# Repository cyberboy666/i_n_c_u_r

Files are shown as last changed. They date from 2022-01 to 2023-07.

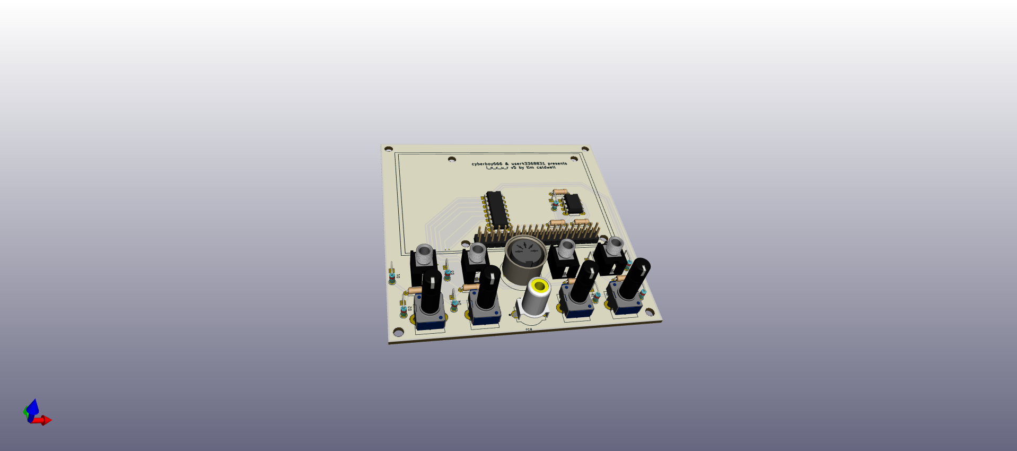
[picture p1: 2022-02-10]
incur_board_3d.png

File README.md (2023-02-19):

# i_n_c_u_r

### a [r_e_c_u_r](https://github.com/cyberboy666/r_e_c_u_r) video sampler extension circuit - adding knobs, cv and serial midi control



- this circuit is distributed by __UNDERSCORES__ - _an open video hardware label_ : it is available to purchase - as a pcb, kit or assembled unit - at [underscores.shop](https://underscores.shop/i_n_c_u_r/)
- the schematic for the circuit can be found [here](/hardware/schematic.pdf)
- the pcb gerber files for the lastest version can be found [here](/hardware/gerber_latest.zip)
- interactive BOM is [here](https://htmlpreview.github.io/?https://github.com/cyberboy666/i_n_c_u_r/blob/main/hardware/bom/ibom.html)
- consider [donating](https://opencollective.com/underscores) to the underscores project to help us continue creating for the commons

## description

__NOTE__ : _i_n_c_u_r_ is an extension circuit for my existing raspberry pi project [r_e_c_u_r](https://github.com/cyberboy666/r_e_c_u_r) - it will only be useful to you if you already have build a r_e_c_u_r

_disclaimer: this is a fun custom project, but dont forget there are other ways to getting serial and cv control over recur parameters. USB midi is supported in recur without any extra circuitry. other [diy](https://aemodular.boards.net/thread/141/simple-cv-midi-converter-arduino) and [commercial](https://www.befaco.org/en/vcmc/) products exist that convert cv to midi, and serial to USB. in my opinion a general solution for cv-to-usb-midi applied to recur is more useful than a specific board that only works with recur_

- 4x __knobs__ for physical control over shader parameters
- 4x __cv jacks (0-5v)__ for sequenced control over shader parameters (from older/analog synths eg eurorack)
- __serial midi__ din5 jack for sequenced control over shader parameters (from older midi devices)
- exposes _rpi video output through rca jack_ (rather than the 3.5mm trrs jack on pi )
- mounting holes and front facing interface parts for easier racking / enclosure building
- interfacing with rpi through gpio leaving all usb jacks free

## demo videos

(https://videos.scanlines.xyz/w/534XkPbbdpDNjTziM6pPNG)

(https://youtu.be/ah2HY1fuv8w?t=638)

# documentation

this project is fully _open-source hardware_ - all the files required to build it are included in this repo for free. if you have the time and/or skill you can contribute back by collaborating on / testing new designs, improving these docs, making demo videos/other creative content etc. you can also support the project financially by [donating directing](https://opencollective.com/underscores), or purchasing through the [web shop](https://underscores.shop).

depending on whether you are going fully diy or buying an assembled and tested unit, some of the following guides will be relavent to you. the flow would be:

## ordering parts

<details><summary><b>parts sourcing guide (w/ notes on pcb fabracation )</b> - start here if you are building fully from scatch or have purchased a pcb</summary>

i try to source all the parts i can from either:
- [tayda](https://www.taydaelectronics.com/) ; cheaper for common parts like resistors etc, also good for mechanical parts like switches and buttons
- [mouser](https://www.mouser.de/) ; has lots more options, speciality video ic's, can sometimes cost more (free shipping on orders over 50euros)
- other ; ocationally there will be parts which will need to be sourced elsewhere - usaully either aliexpress, ebay or amazon etc...

take a look at the [full_bom](/hardware/bom/full_bom.csv) for this project to see where i am sourcing each part from

## import into tayda

- go to the [tayda quick order](https://www.taydaelectronics.com/quick-order/) and in bottom corner choose _add from file_
- select the file [tayda_bom.csv](./hardware/bom/tayda_bom.csv) in the BOM folder (you will have to download it first or clone this repo)
- after importing select _add to cart_
- __NOTE:__ the minimum value for resistors is 10, so you may need to modify these values to add to cart (or if they are already modified here you will need to see the  full_bom for actual part QTY) 

- OPTIONAL: it is a good idea to add some dip-ic sockets and 2.54pin headers/sockets to your tayda order if you dont have them around already
  
## import into mouser

- go to [mouser bom tool](https://nz.mouser.com/Bom/) and click _upload spreadsheet_
- select the file [mouser_bom.csv](./hardware/bom/mouser_bom.csv) in this folder (you will have to download it first or clone this repo), then _upload my spreadsheet_ and _next_
- ensure that __Mouser Part Number__ is selected in the dropdown above the first row, then _next_, _process_
- if everything looks correct can now put _add to basket_

# ordering pcbs

you can support this project by buying individual pcbs from the [shop](https://underscores.shop). if you would rather have pcbs fabricated from gerbers directly the file you need is [here](/hardware/gerber_latest.zip) 

- i get my pcbs fabricated from [jlcpcb](https://cart.jlcpcb.com/quote) - 5 is the minumum order per design
- upload the zip file with the `add gerber file` button
- the default settings are mostly fine - set the __PCB Qty__ and __PCB Color__ settings (you can check that the file looks correct with pcb veiwer)
- it may be best to combine orders with other pcbs you want to have fab'd since the shipping can cost more than the items - also orginising group buys is a good way to distribute the extra pcbs /costs 
  
i often use jlcpcb because they are reliable, cheap and give you an option of colours. remember though that the cheapest Chinese fab houses are not always the most ethical or environmently friendly - if you can afford it consider supporting local companies. 

</details>

## assembly guide

<details><summary><b>assembly guide</b> - start here if you have purchased a diy kit</summary>

## interactive BOM for build guiding

follow this link to view the [interactive BOM](https://htmlpreview.github.io/?https://github.com/cyberboy666/i_n_c_u_r/blob/main/hardware/bom/ibom.html)

## general solder advices

- remember to heat pad first (2-3seconds), then add solder, then continue to heat (1-2seconds)

- Checkout the web-comic [soldering is easy](https://mightyohm.com/files/soldercomic/FullSolderComic_EN.pdf) for more soldering advice

## general order of assembly

- in general while assembling i start placing resistors and capacitors first. placing 5 - 10 components at a time and then flipping the board to solder them and trim the legs etc.
- next i would do diodes, transistors and ic's - taking care that these are placed in the right direction (using a ic socket can be useful)
- finally i place the interface parts - rca jacks, power jack, pots and switches - make sure these have lots of solder on for structural stablity

## slightly more specific assembly advice

start with the lowest to place components : resistors, diodes, ic's

next i would place the two headers since soldering from the top can be awkward with too many components - __NOTE these need to be placed upside down!__ ,:

- J8 needs the pins facing up from top of pcb so the screen can go ontop and raspberry pi can go underneath
- J6 also needs to soldered from the top so a jumper from the pi board can be run to bottom of circuit

finally place the pots and jacks.
  
### rca video-out

if you want RCA video out from the pi on this pcb a jumper needs to be run from J6 to the composite video out on the raspberry pi board. on pi0 this is a labeled pin, however on pi3 you will need to solder directly to the board. i used a header-cable, cut one side to be soldered. The pin on pi3 is marked as PP24.

 [picture coming soon]
  
</details>
  
## operating guide
  
<details><summary><b>operating guide</b> - start here if you have purchased an assembled unit</summary>



- to enable the analog inputs ( knobs & cv ) go to `user_input` folder in r_e_c_u_r's `_SETTINGS_` tab and toggle `ANALOG_INPUT`
- to enable serial midi input go to `user_input` folder in r_e_c_u_r's `_SETTINGS_` tab and toggle `MIDI_INPUT` to _serial_
  
for more info on operating r_e_c_u_r see this [guide](https://github.com/cyberboy666/r_e_c_u_r/wiki/operate_docs)

</details>

### more info

<details><summary><b>how the circuit works</b></summary>

</details>

<details><summary><b>contributing guide</b></summary>
  
if you would like to contribute back to these projects in some way but dont know how the best thing (for now) would be to reach out to me directly ( tim@cyberboy666.com or @cyberboy666 on scanlines forum) - i will be happy to help
  
</details>

## community contributed enclosure designs:

- an [eurorack panel design](enclosure/i_n_c_u_r%20_%20eurorack_panel.stl) by [Simon Gorzelnik](https://www.instagram.com/shimon.jpg/)
- a [base enclosure](enclosure/INCUR%20enclosure%20base.stl) by [miles](mailto:milesjohnsonwashere@gmail.com)

## credits & more info

This circuit is distributed through UNDERSCORES – open video hardware label – visit [underscores.shop](https://underscores.shop) for more info

The pcb was designed using KICAD

Everything from gerbers, cad files, panels and documentation is freely available online and distributed under CC-BY-SA / open-source licenses – help us contribute to the commons !

Ask any questions or start discussions related to this project on the [scanlines.xyz](https://scanlines.xyz) forum – an online community space dedicated to diy av / electronic media art

You can contact me directly at tim (at) cyberboy666 (dot) com 
Please get in touch if you are interested in hosting a workshop !



Thanks to Signal Culture for giving me the time and space to explore. to Bastien Lavaud for circuit advice, always. To Ben Caldwell for project advice. To everyone who has or will contribute ♥♥♥

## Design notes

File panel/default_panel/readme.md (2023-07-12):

# i_n_c_u_r default_panel notes

- the mounting holes fit m3 screws
- the front_panel mounts to pcb with 15mm standoffs
- 45mm screws will fit front_panel, pcb, raspberry_pi_3 and back_plate
- power is provided via 5v 1.5A micro_usb directly to raspberry pi
- the default potentiometers in underscores BOMs have 12mm shaft lengths - due to 15mm standoff you will need to replace these with >17mm shaft length alternatives if you plan to use it with a panel

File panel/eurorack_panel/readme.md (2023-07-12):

# i_n_c_u_r eurorack_panel notes

- the mounting holes fit m3 screws
- the front_panel mounts to pcb with 15mm standoffs
- this circuit mounts a raspberry_pi_3 with total depth of ?????
- power is provided via 5v 1.5A micro_usb directly to raspberry pi
- this panel includes UNTESTED YET mounting holes for usb and hdmi breakout cables
- this panel is 20HP
- the default potentiometers in underscores BOMs have 12mm shaft lengths - due to 15mm standoff you will need to replace these with >17mm shaft length alternatives if you plan to use it with a panel

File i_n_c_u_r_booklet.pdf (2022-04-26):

### cyberboy666 & underscores.shop present a r_e_c_u_r video sampler extension circuit

# i_n_c_u_r

## adding knobs, cv and serial midi control

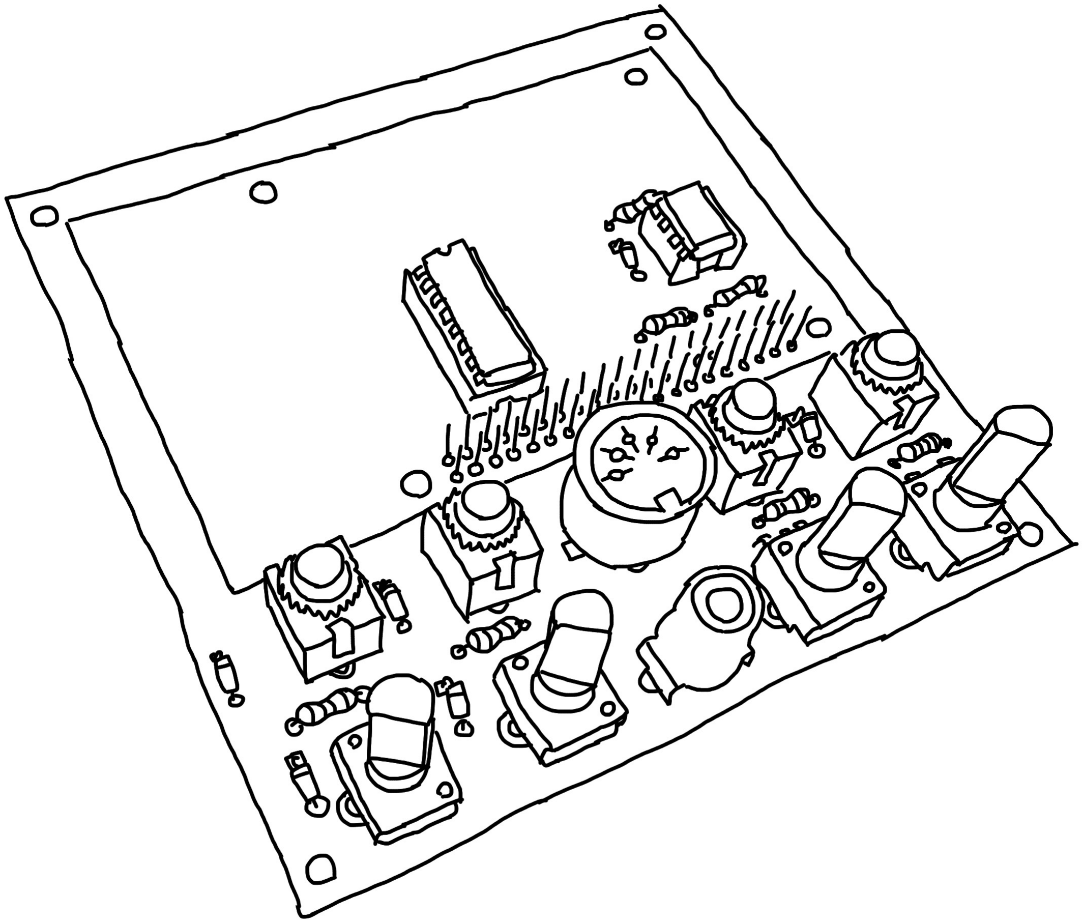
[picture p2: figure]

## instruction manual and build guide

V5

View this project online at underscores.shop/i_n_c_u_r

## BACKGROUND

using r_e_c_u_r you can run shaders which generate and process video. there are a few different options for controlling the parameters of these shaders – a midi controller connected via usb is the most common. adding i_n_c_u_r to your setup gives you even more options:

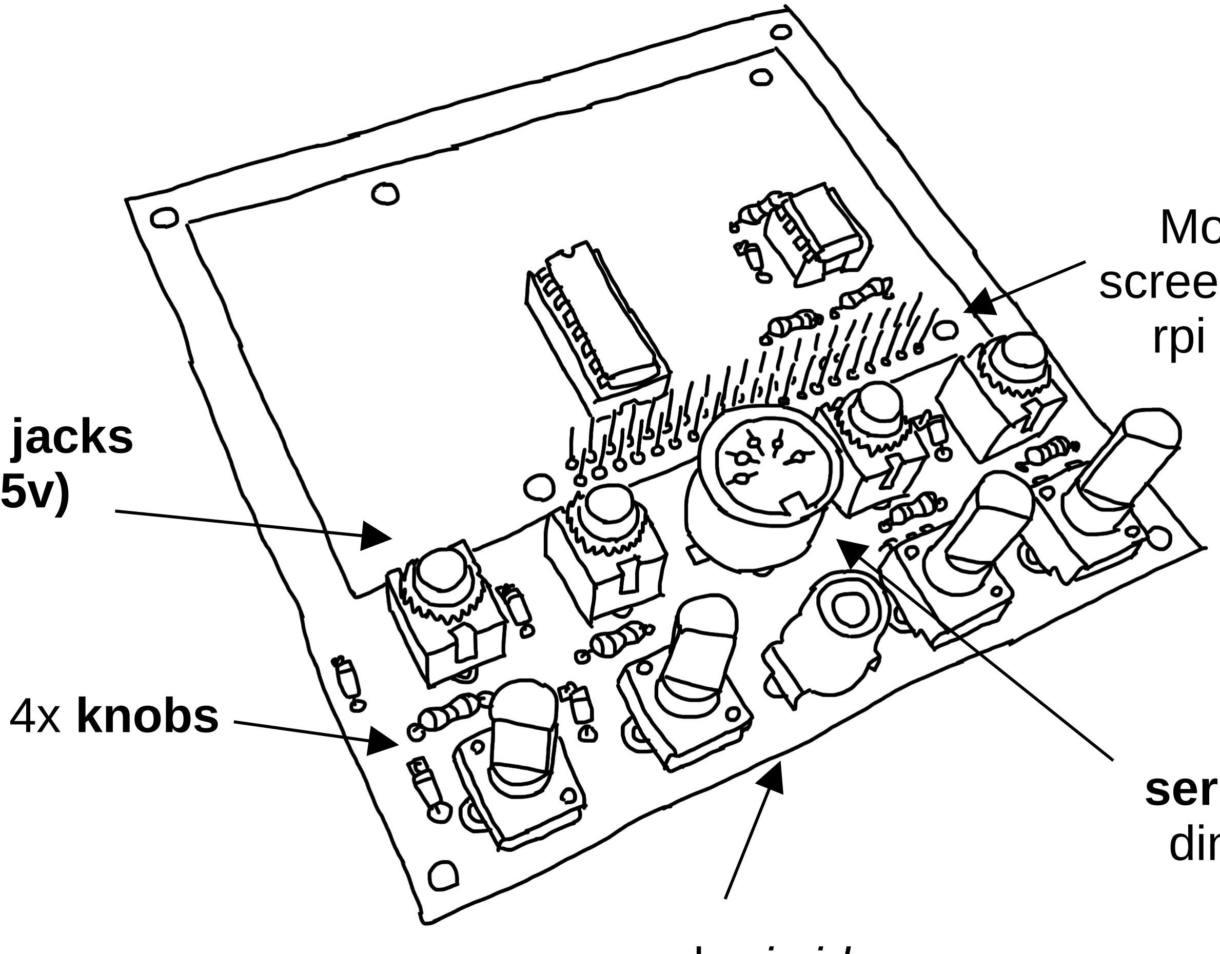
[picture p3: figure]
4x knobs

- 4x knobs for physical control over shader parameters
- 4x cv jacks (0-5v) for sequenced control over shader parameters (from older/analog synths eg eurorack)
- serial midi din5 jack for sequenced control over shader parameters (from older midi devices)
- exposes rpi video output through rca jack (rather than the 3.5mm trrs jack on pi )
- mounting holes and front facing interface parts for easier racking / enclosure building
- interfacing with rpi through gpio leaving all usb jacks free

## exposed rpi video

output through rca

4x cv jacks
(0-5v)

serial midi
din5 jack

Mounting for
screen on top and
rpi on bottom

## BUILD INSTRUCTIONS

Use the Interactive BOM to help place parts - kutt.it/QM4fh9

- remember to heat pad first (2-3seconds), then add solder, then continue to heat (1-2seconds) Checkout the web-comic soldering is easy for more soldering advice.
- start with the resistors, taking care place the correct value in the correct footprint - direction does not matter. Place a few resistors in (as many as you are comfortable with) then solder and trim legs
- next place the diodes - take note of the direction - black bar on component matching black bar on footprint

●
- now lets do the ic/sockets -> make sure the direction is correct! place in and fold two corner pins to hold in place, then solder all pins. you can place the ic in now too.
- next i would place the two headers since soldering from the top can be awkward with too many components - NOTE these need to be placed upside down! J8 needs the pins facing up from top of pcb so the screen can go ontop and raspberry pi can go underneath. J6 also needs to soldered from the top so a jumper from the pi board can be run to bottom of circuit
- finally place the pots and jacks – make sure to use plenty of solder here for structural support

rca video-out

if you want RCA video out from the pi on this pcb a jumper needs to be run from J6 to the composite video out on the raspberry pi board. on pi0 this is a labeled pin, however on pi3 you will need to solder directly to the board. i used a header-cable, cut one side to be soldered. The pin on pi3 is marked as PP24.

## OPERATING GUIDE

- to enable the analog inputs ( knobs & cv ) go to the user_input folder in r_e_c_u_r's SETTINGS tab and toggle ANALOG_INPUT to on
- to enable serial midi input go to user_input folder in r_e_c_u_r's SETTINGS tab and toggle MIDI_INPUT to serial

for more info on operating r_e_c_u_r see the projects github page

## CREDITS AND MORE INFO

This circuit is distributed through UNDERSCORES – open video hardware label – visit underscores.shop for more info

The pcb was designed using KICAD , this booklet was created in LibreOffice Draw

Everything from gerbers, cad files, panels and documentation is freely available online and distributed under CC-BY-SA / open-source licenses – help us contribute to the commons !

Ask any questions or start discussions related to this project on the scanlines.xyz forum – an online community space dedicated to diy av / electronic media art

You can contact me directly at tim (at) cyberboy666 (dot) com Please get in touch if you are interested in hosting a
workshop !

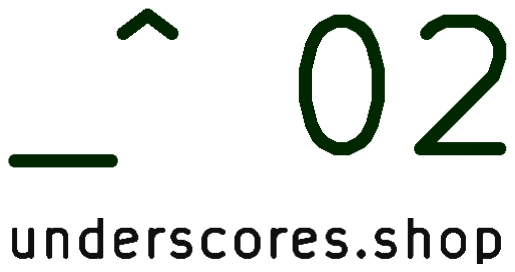
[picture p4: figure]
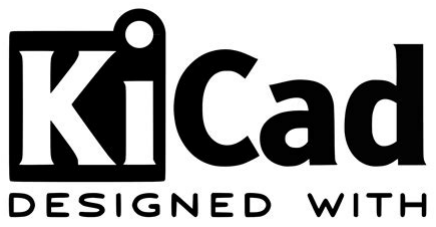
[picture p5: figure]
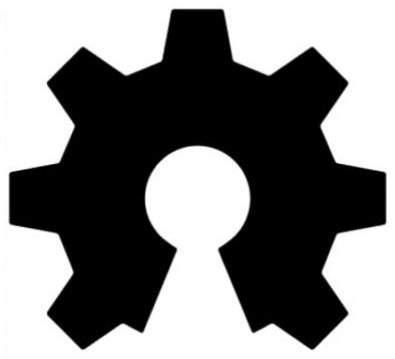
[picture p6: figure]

Thanks to Signal Culture for giving me the time and space to explore this project. to Bastien Lavaud for circuit advice, always. To Ben Caldwell for project advice. To everyone who has or will contribute ♥♥♥

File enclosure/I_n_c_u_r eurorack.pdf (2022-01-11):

R_E_C_U_R (https://cyberboy666.com/recur/) / I_N_C_U_R (https://github.com/langolierz/r_e_c_u_r/wiki/i_n_c_u_r_pcb)
Eurorack Paneldesign by Simon Gorzelnik (https://www.instagram.com/shimon.jpg/)
3D Printer files for eurorack implementation of the i_n_c_u_r PCB.
20HP

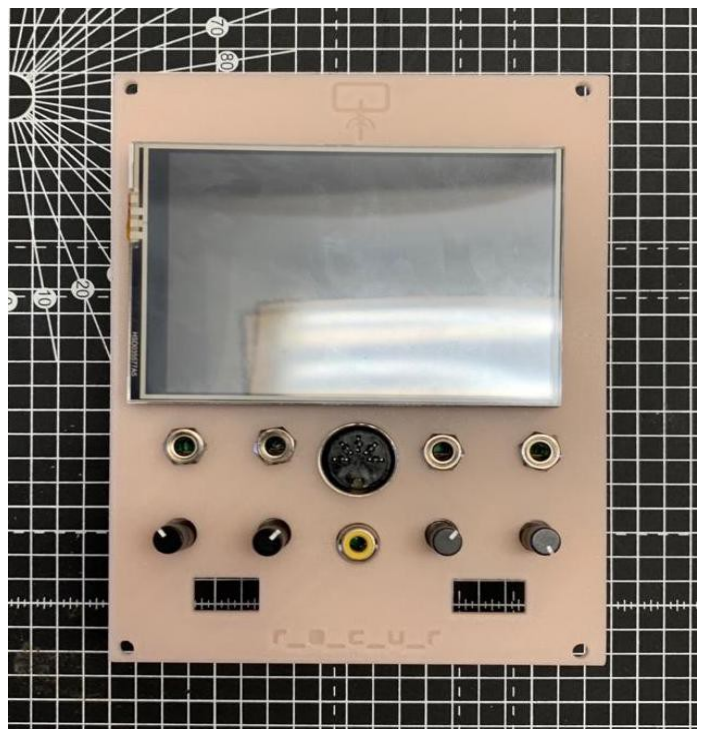
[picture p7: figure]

STL print file (https://drive.google.com/file/d/1pA-2IYGiMDZ4ewx3A1R4QjFpB-08Ej5R/view?usp=sharing)

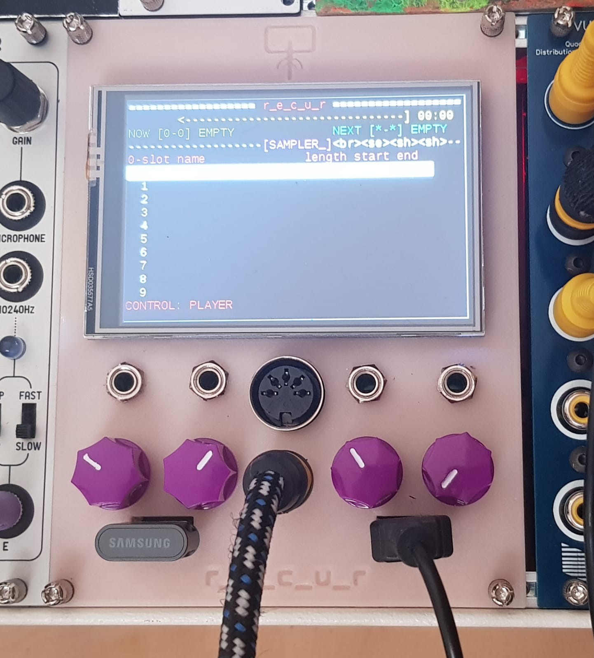
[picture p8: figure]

STEP file (https://drive.google.com/file/d/1E1lQi2ROnBsBw4icBrbuerrlihWayVE4/view?usp=sharing) (if you want to do some changes) You need:
2 x USB Extension (https://www.amazon.de/gp/product/B000VN4NX6/ref=ppx_yo_dt_b_search_asin_title?ie=UTF8&psc=1)

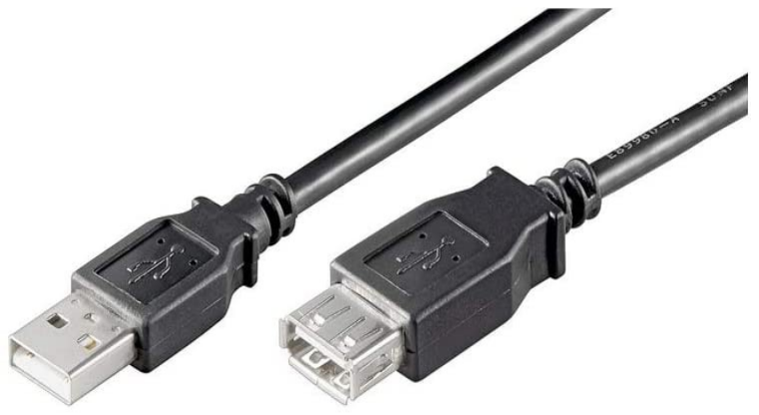
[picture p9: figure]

If you use the design you can donate via paypal to Simongorz@yahoo.de

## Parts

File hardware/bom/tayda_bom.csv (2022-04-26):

sku | qty | ref | val | vendor
A-1095 | 8 | D1 D2 D3 D4 D5 D6 D7 D8 | BAT46 | tayda
A-157 | 1 | D9 | 1N4148 | tayda
A-2563 | 4 | J1 J2 J3 J4 | mono_jack_3.5mm | tayda
A-2200 | 4 | R1 R2 R3 R4 | 1K | tayda
A-2246 | 1 | R5 | 220 | tayda
A-2248 | 1 | R6 | 100K | tayda
A-2247 | 1 | R7 | 470 | tayda
A-5531 | 4 | RV1 RV2 RV3 RV4 | 10k_pot | tayda
A-2470 | 1 | U1 | MCP3008 | tayda

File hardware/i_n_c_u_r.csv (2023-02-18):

Reference | Quantity | Value | Footprint | Datasheet | Field4 | Field5
D1 D2 D3 D4 D5 D6 D7 D8 | 8 | BAT46 | Diodes_THT:D_DO-35_SOD27_P5.08mm_Vertical_KathodeUp
D9 | 1 | 1N4148 | Diodes_THT:D_DO-35_SOD27_P5.08mm_Vertical_KathodeUp
J1 J2 J3 J4 | 4 | mono_jack_3.5mm | lib_fp:Jack_3.5mm_QingPu_WQP-PJ398SM_Vertical_CircularHoles
J5 | 1 | din5 | lib_fp:tht_vertical_din5
J6 | 1 | Conn_01x01 | Pin_Headers:Pin_Header_Straight_1x01_Pitch2.54mm
J7 | 1 | rca | lib_fp:tht_rca_vertical | CUI Inc | Manufacturer recommendations | B
J8 | 1 | 2x20_Extra_Tall_Socket_Header | Connector_PinHeader_2.54mm:PinHeader_2x20_P2.54mm_Vertical
R1 R2 R3 R4 | 4 | 1K | Resistors_THT:R_Axial_DIN0207_L6.3mm_D2.5mm_P7.62mm_Horizontal
R5 | 1 | 220 | Resistors_THT:R_Axial_DIN0207_L6.3mm_D2.5mm_P7.62mm_Horizontal
R6 | 1 | 100K | Resistors_THT:R_Axial_DIN0207_L6.3mm_D2.5mm_P7.62mm_Horizontal
R7 | 1 | 470 | Resistors_THT:R_Axial_DIN0207_L6.3mm_D2.5mm_P7.62mm_Horizontal
RV1 RV2 RV3 RV4 | 4 | 10k_pot | lib_fp:tht_vertical_potentiometer
U1 | 1 | MCP3008 | Housings_DIP:DIP-16_W7.62mm_LongPads
U2 | 1 | 6N138 | Housings_DIP:DIP-8_W7.62mm_LongPads

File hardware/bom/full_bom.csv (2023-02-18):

sku | qty | ref | val | vendor
A-1095 | 8 | D1 D2 D3 D4 D5 D6 D7 D8 | BAT46 | tayda
A-157 | 1 | D9 | 1N4148 | tayda
A-2563 | 4 | J1 J2 J3 J4 | mono_jack_3.5mm | tayda
490-SD-50BV | 1 | J5 | din5 | mouser
- | 1 | J6 | Conn_01x01 | -
490-RCJ-024 | 1 | J7 | rca | mouser
485-1979 | 1 | J8 | 2x20_Extra_Tall_Socket_Header | mouser
A-2200 | 4 | R1 R2 R3 R4 | 1K | tayda
A-2246 | 1 | R5 | 220 | tayda
A-2248 | 1 | R6 | 100K | tayda
A-2247 | 1 | R7 | 470 | tayda
A-5531 | 4 | RV1 RV2 RV3 RV4 | 10k_pot | tayda
A-2470 | 1 | U1 | MCP3008 | tayda
859-6N138 | 1 | U2 | 6N138 | mouser

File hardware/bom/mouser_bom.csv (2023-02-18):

sku | qty | ref | val | vendor
490-SD-50BV | 1 | J5 | din5 | mouser
490-RCJ-024 | 1 | J7 | rca | mouser
485-1979 | 1 | J8 | 2x20_Extra_Tall_Socket_Header | mouser
859-6N138 | 1 | U2 | 6N138 | mouser

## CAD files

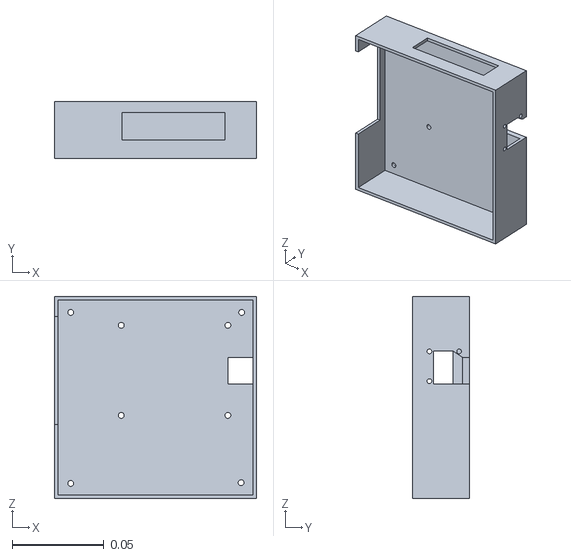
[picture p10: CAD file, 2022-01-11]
enclosure/INCUR enclosure base.stl
0.11 x 0.0308 x 0.11

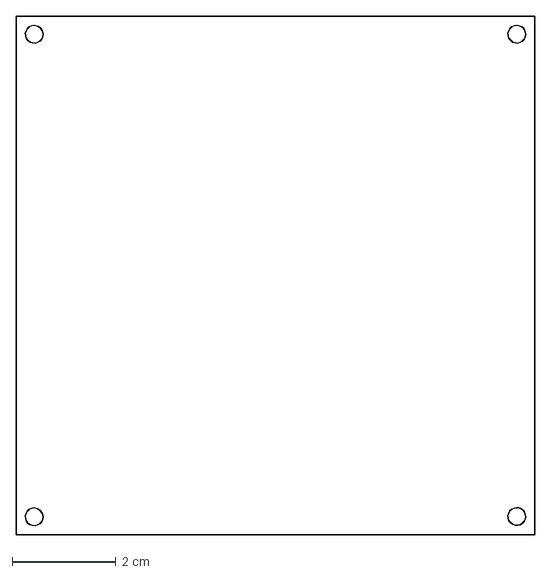
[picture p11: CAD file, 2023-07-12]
panel/back_panel/back_panel-Edge_Cuts.dxf
10.0 x 10.0 cm

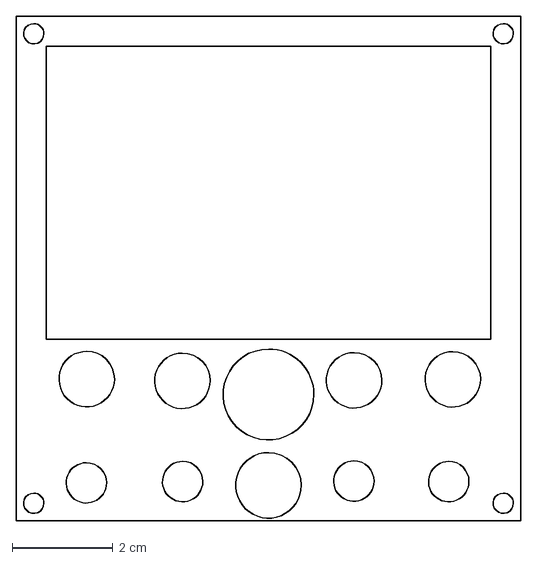
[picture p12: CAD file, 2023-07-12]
panel/default_panel/i_n_c_u_r-Edge_Cuts.dxf
10.0 x 10.0 cm

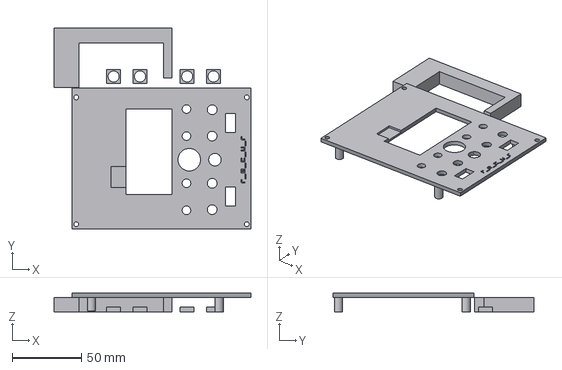
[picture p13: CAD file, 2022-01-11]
enclosure/i_n_c_u_r _ eurorack_panel.step
142.0 x 145.0 x 13.5 mm

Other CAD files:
enclosure/i_n_c_u_r _ eurorack_panel.stl
panel/default_panel/i_n_c_u_r-F_Silkscreen.dxf

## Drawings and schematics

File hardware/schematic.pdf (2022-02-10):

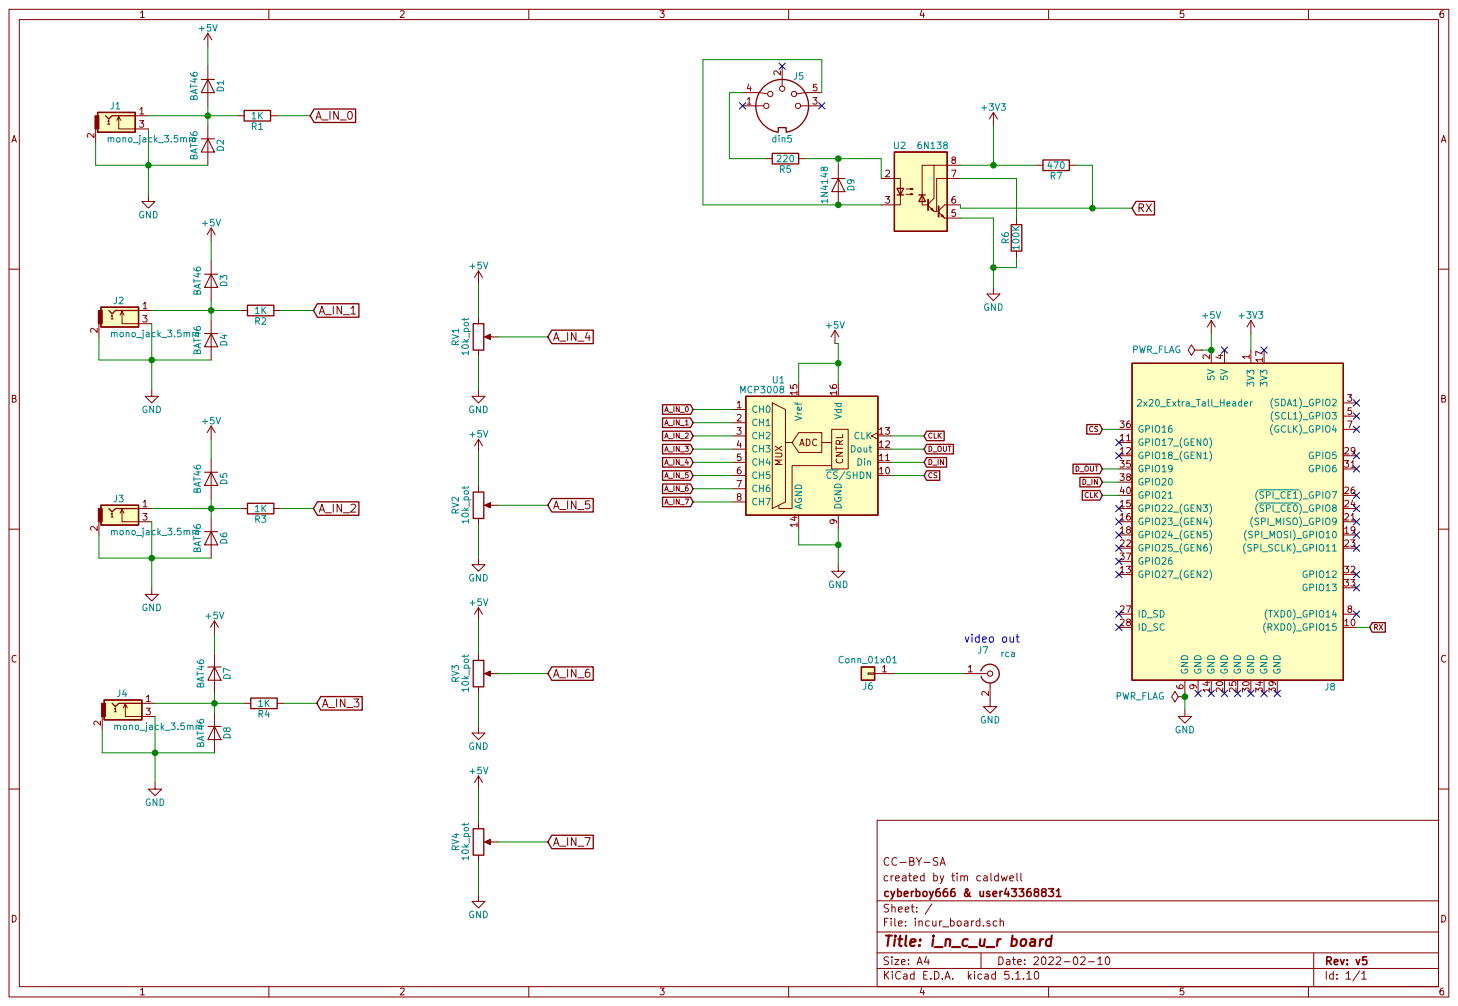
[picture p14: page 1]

created by tim caldwell CC-BY-SA

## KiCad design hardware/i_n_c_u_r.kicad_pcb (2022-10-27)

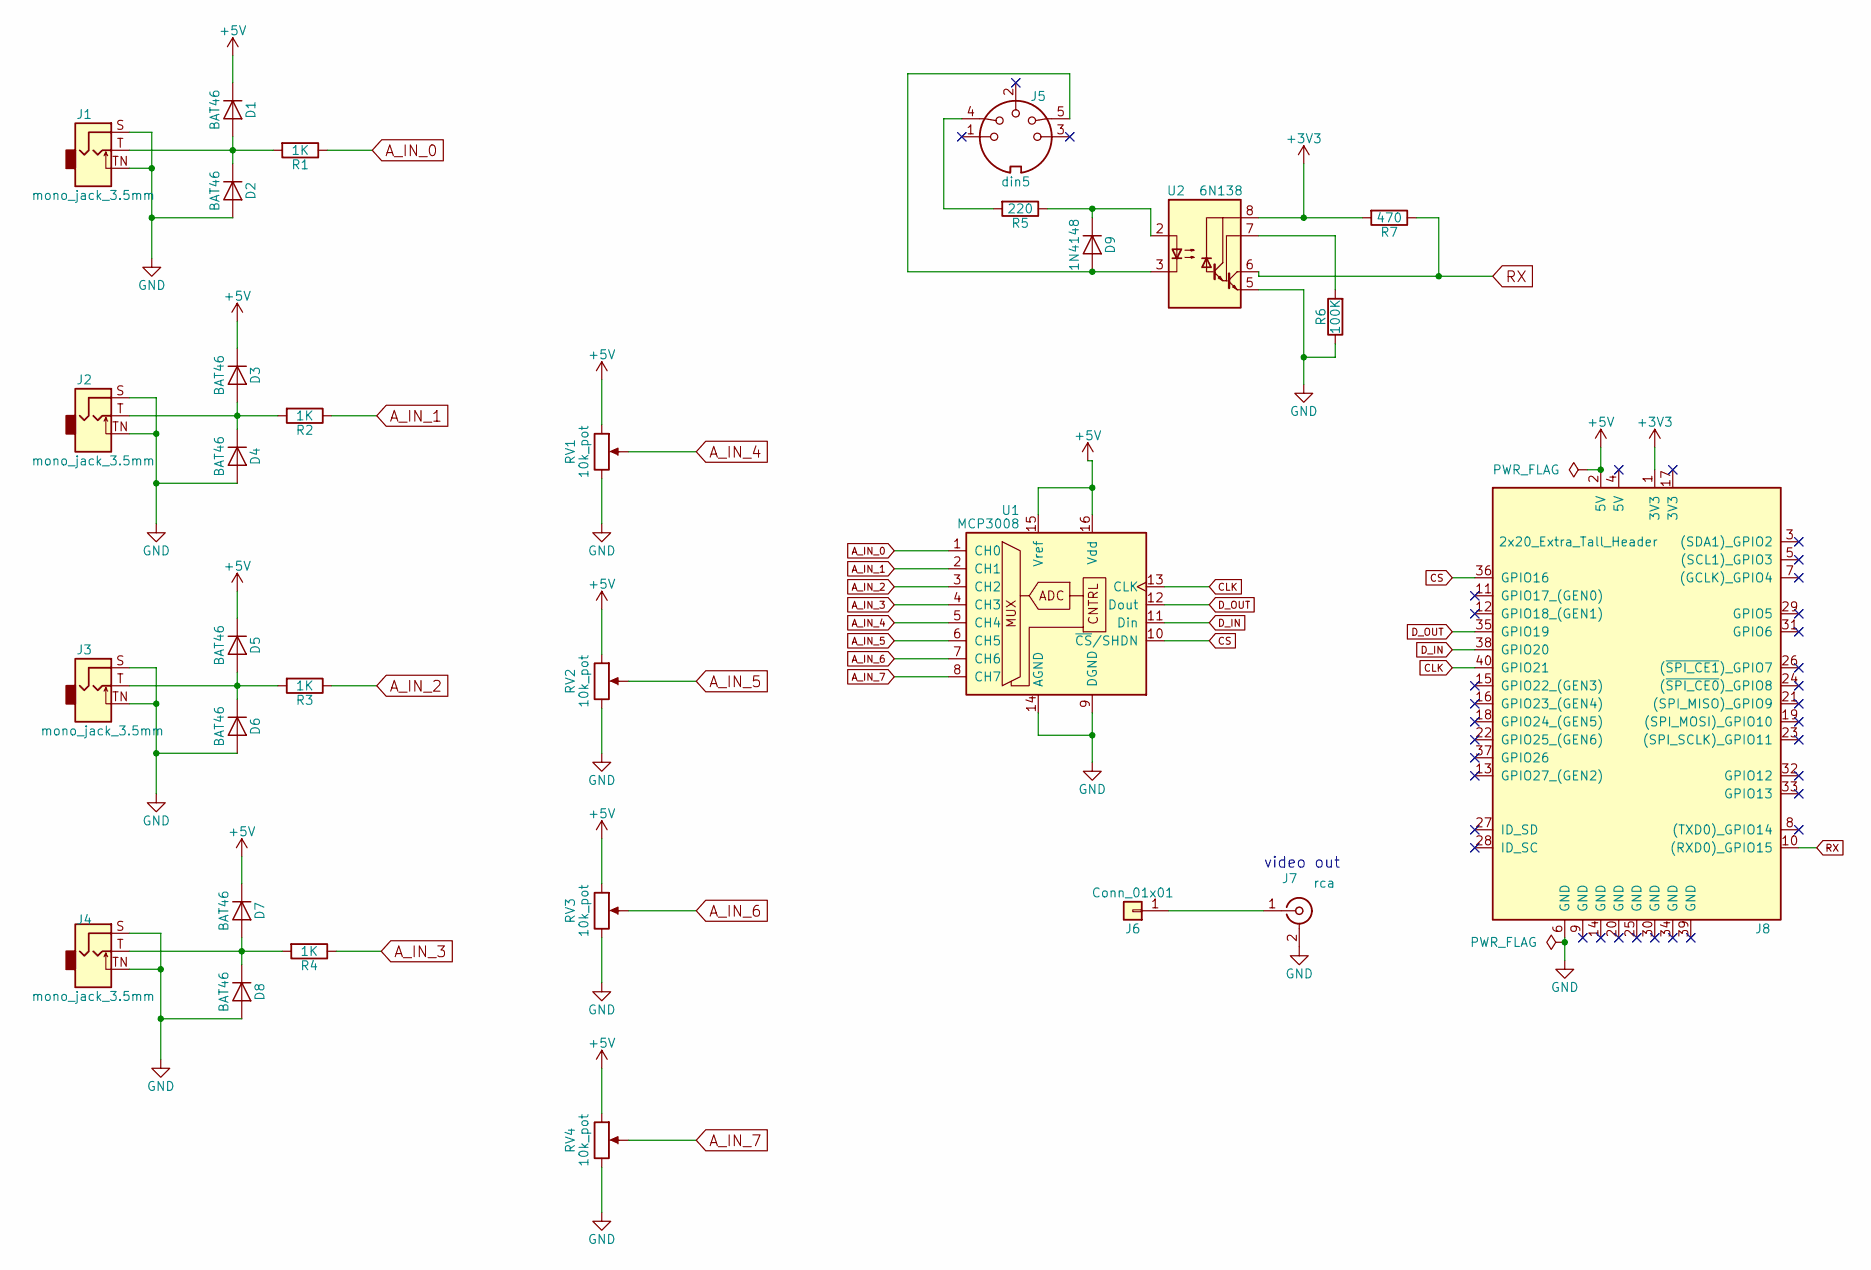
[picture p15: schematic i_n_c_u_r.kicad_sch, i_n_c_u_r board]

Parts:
D1, D2, D3, D4, D5, D6, D7, D8: BAT46; D_DO-35_SOD27_P5.08mm_Vertical_KathodeUp
D9: 1N4148; D_DO-35_SOD27_P5.08mm_Vertical_KathodeUp
J1, J2, J3, J4: mono_jack_3.5mm; Jack_3.5mm_QingPu_WQP-PJ398SM_Vertical_CircularHoles
J5: din5; tht_vertical_din5
J6: Conn_01x01; Pin_Header_Straight_1x01_Pitch2.54mm
J7: rca; tht_rca_vertical
J8: 2x20_Extra_Tall_Header; PinHeader_2x20_P2.54mm_Vertical
R1, R2, R3, R4: 1K; R_Axial_DIN0207_L6.3mm_D2.5mm_P7.62mm_Horizontal
R5: 220; R_Axial_DIN0207_L6.3mm_D2.5mm_P7.62mm_Horizontal
R6: 100K; R_Axial_DIN0207_L6.3mm_D2.5mm_P7.62mm_Horizontal
R7: 470; R_Axial_DIN0207_L6.3mm_D2.5mm_P7.62mm_Horizontal
RV1, RV2, RV3, RV4: 10k_pot; tht_vertical_potentiometer
U1: MCP3008; DIP-16_W7.62mm_LongPads
U2: 6N138; DIP-8_W7.62mm_LongPads

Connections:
+3V3: J8.1 (3V3), R7.2, U2.8 (VCC)
+5V: D1.1 (K), D3.1 (K), D5.1 (K), D7.1 (K), J8.2 (5V), RV1.1, RV2.1, RV3.1, RV4.1, U1.15 (Vref), U1.16 (Vdd)
A_IN_0: R1.1, U1.1 (CH0)
A_IN_1: R2.1, U1.2 (CH1)
A_IN_2: R3.1, U1.3 (CH2)
A_IN_3: R4.1, U1.4 (CH3)
A_IN_4: RV1.2, U1.5 (CH4)
A_IN_5: RV2.2, U1.6 (CH5)
A_IN_6: RV3.2, U1.7 (CH6)
A_IN_7: RV4.2, U1.8 (CH7)
CLK: J8.40 (GPIO21), U1.13 (CLK)
CS: J8.36 (GPIO16), U1.10 (~CS/SHDN)
D_IN: J8.38 (GPIO20), U1.11 (Din)
D_OUT: J8.35 (GPIO19), U1.12 (Dout)
GND: D2.2 (A), D4.2 (A), D6.2 (A), D8.2 (A), J1.S, J1.TN, J2.S, J2.TN, J3.S, J3.TN, J4.S, J4.TN, J7.2 (Ext), J8.6 (GND), R6.1, RV1.3, RV2.3, RV3.3, RV4.3, U1.9 (DGND), U1.14 (AGND), U2.5 (GND)
unnamed: D1.2 (A), D2.1 (K), J1.T, R1.2
unnamed: D3.2 (A), D4.1 (K), J2.T, R2.2
unnamed: D7.2 (A), D8.1 (K), J4.T, R4.2
unnamed: D9.1 (K), R5.1, U2.2 (C1)
unnamed: D9.2 (A), J5.5, U2.3 (C2)
unnamed: D5.2 (A), D6.1 (K), J3.T, R3.2
unnamed: J5.4, R5.2
unnamed: J6.1, J7.1 (In)
unnamed: R6.2, U2.7 (VO1)
RX: J8.10 ((RXD0)_GPIO15), R7.1, U2.6 (VO2)

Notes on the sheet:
video out

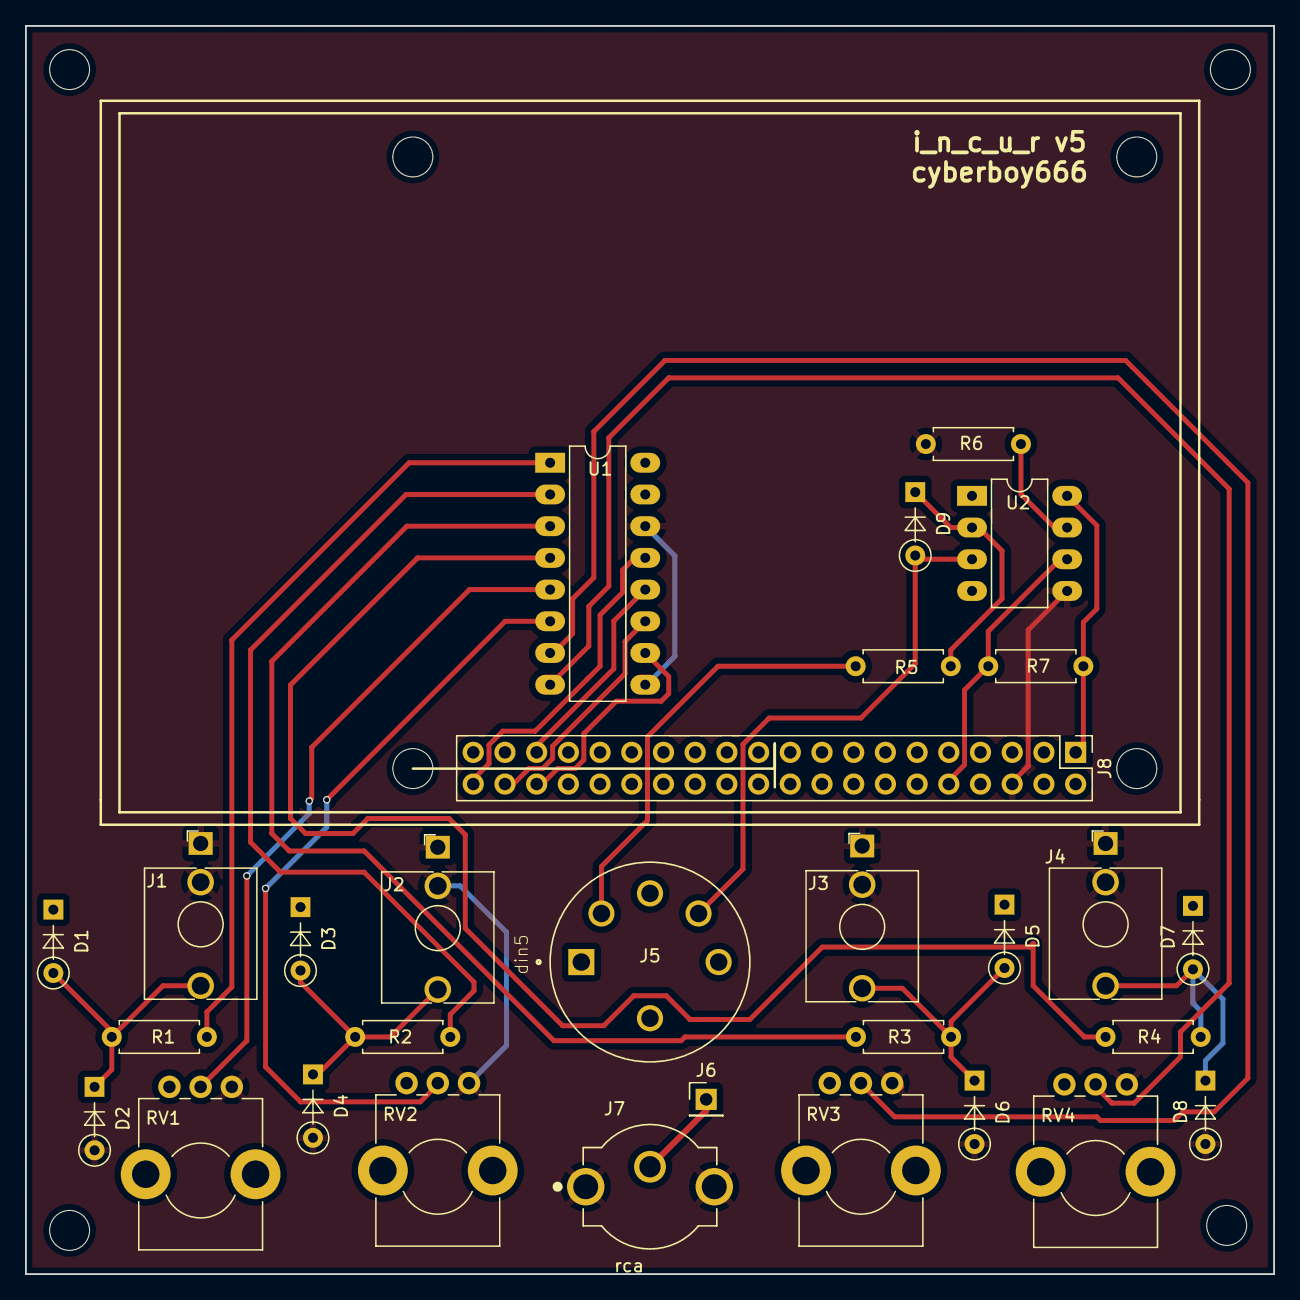
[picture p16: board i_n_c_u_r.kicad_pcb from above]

Board: 2 copper layers, 100.0 x 100.0 mm, 30 parts (0 on the bottom side), 25 nets.

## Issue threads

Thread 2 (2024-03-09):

mcp3008 runs at 5v but rpi pins are only rated for 3v3

cyberboy666, 2024-03-09:
the data_out from mcp3008 is sending spi at 5v, whereas pi input gpios are only rated for 3v3. in practice this doesnt seem to be an issue, however it would be good practice to level shift this, or atleast voltage divide it before sending into the pi gpio

heres a [stackexchange](https://raspberrypi.stackexchange.com/questions/38973/are-the-spi-pins-5v-tolerant) discussing it

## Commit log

2022-01-11 migrate to own repo
    [INCUR enclosure base.stl, i_n_c_u_r _ eurorack_panel.step, i_n_c_u_r _ eurorack_panel.stl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]
2022-02-10 plot schematic
    [incur_board.kicad_pcb]
2022-02-22 renaming schematic
    [incur_board.sch]
2022-02-22 rename kicad board
    [i_n_c_u_r.kicad_pcb, i_n_c_u_r.sch]
2022-02-28 update bom
    [full_bom.csv, i_n_c_u_r.csv, mouser_bom.csv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]
2022-10-27 made pot holes bigger - small updates for kicad6
    [i_n_c_u_r-B_Cu.gbr, i_n_c_u_r-B_Mask.gbr, i_n_c_u_r-B_Silkscreen.gbr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]
2023-07-12 add panel stuff
    [back_panel-Edge_Cuts.dxf, back_panel.kicad_pcb, back_panel.kicad_sch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]
